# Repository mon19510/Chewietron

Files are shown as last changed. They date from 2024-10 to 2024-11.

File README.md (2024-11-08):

# Chewietron
Este repositorio contiene el código, modelos 3D y la documentación para un robot cuadrúpedo de 12 DOF, controlado mediante cinemática inversa. El objetivo es implementar un sistema de control que permita al robot realizar movimientos precisos y estáticos mediante el control de cada una de sus articulaciones. Fue nombrado en honor a mi perro, Chewie.

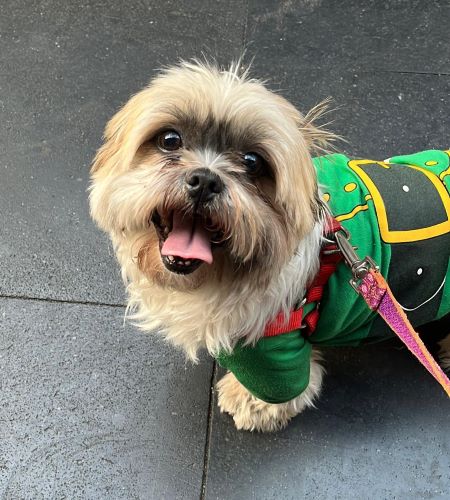
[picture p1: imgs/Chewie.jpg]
Chewie original


Este robot cuadrúpedo fue diseñado para estudiar y aplicar conceptos de cinemática inversa en un sistema físico. El robot cuenta con tres grados de libertad por pata, permitiéndole moverse de forma independiente en cada articulación. El control de cada servo se realiza utilizando un controlador PCA9685 conectado a un microcontrolador UM Tiny S3 (ESP32-S3), que calcula los ángulos de movimiento necesarios para cada pata con base en la posición deseada.

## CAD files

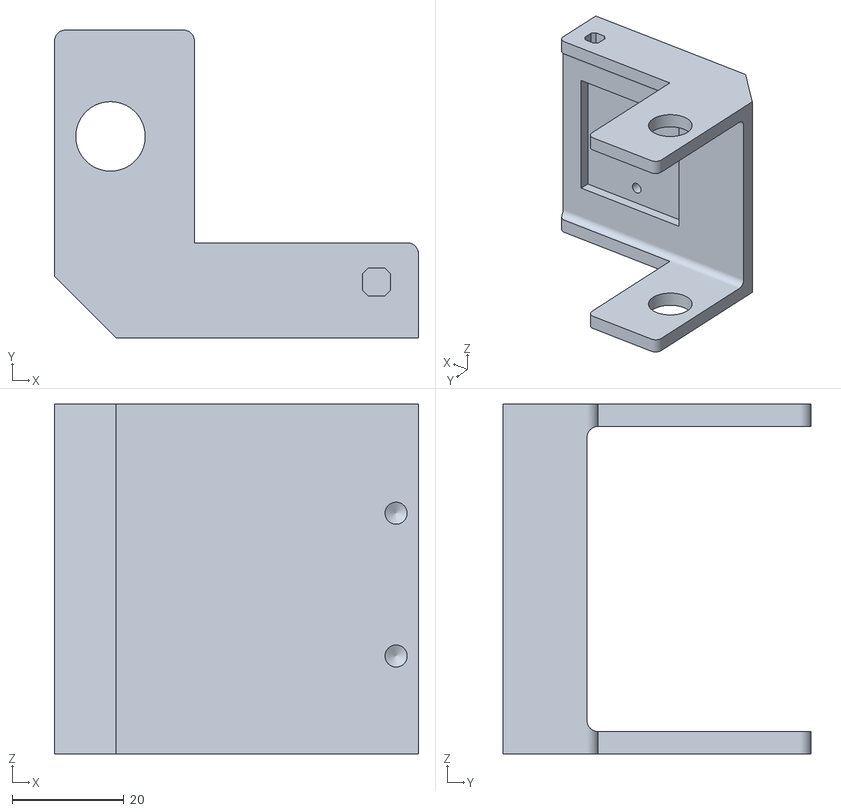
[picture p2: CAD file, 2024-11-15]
CADS/STLs GIT/BASEPRINCIPAL_PATA_DER_FRONTAL.stl
65.0 x 55.0 x 62.5

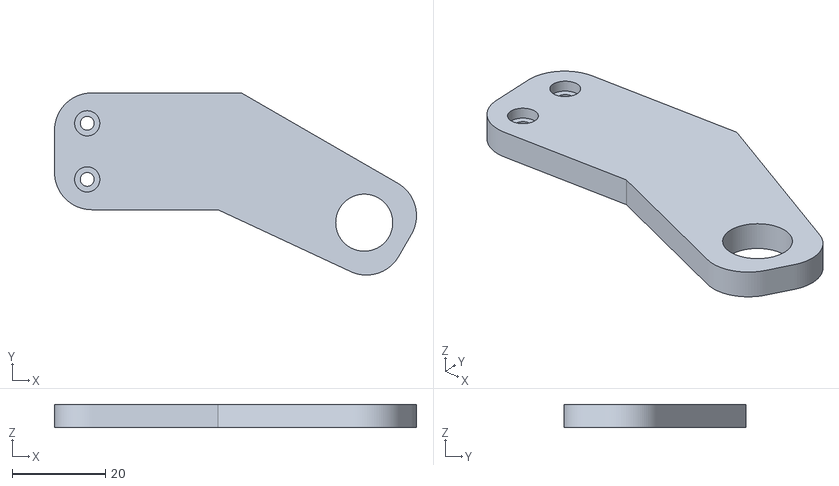
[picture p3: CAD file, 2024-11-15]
CADS/STLs GIT/PATA_SUP_DER_COJINETE.stl
77.5 x 39.0 x 5.00

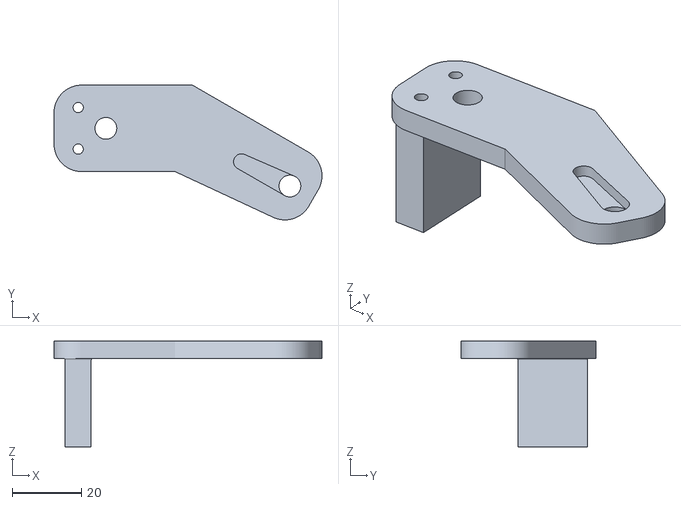
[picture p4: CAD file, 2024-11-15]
CADS/STLs GIT/PATA_SUP_IZQ_SIMPLE.stl
77.5 x 39.0 x 30.5

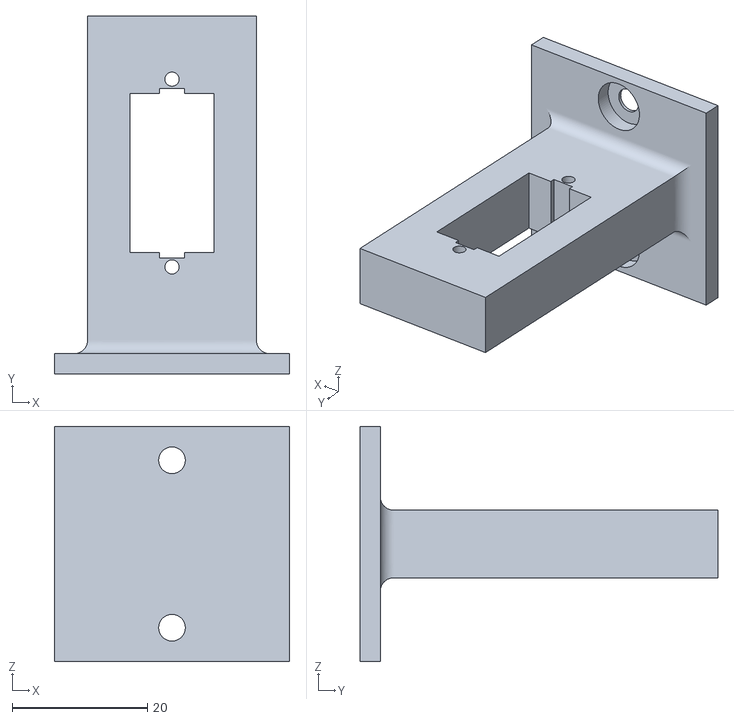
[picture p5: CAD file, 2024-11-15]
CADS/STLs GIT/BASEMOTOR_ENGRANE.stl
34.8 x 53.0 x 34.8

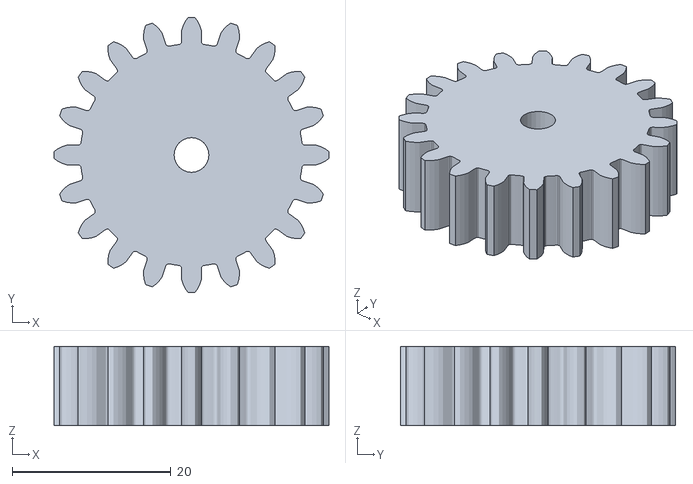
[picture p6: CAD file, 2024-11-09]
CADS/STLs GIT/ENGRANE_HOMBRO.stl
34.6 x 34.6 x 10.0

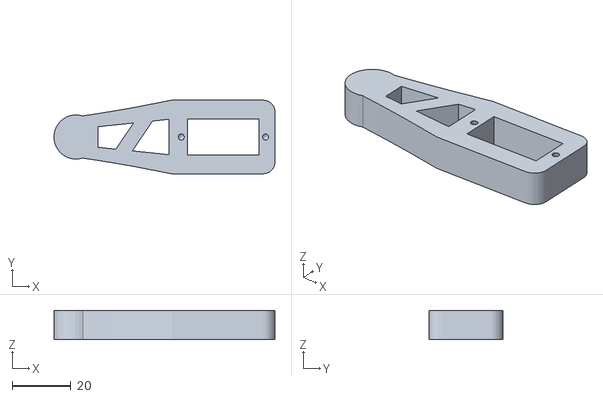
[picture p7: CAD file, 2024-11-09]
CADS/STLs GIT/PATA_INF.stl
75.0 x 25.0 x 10.0

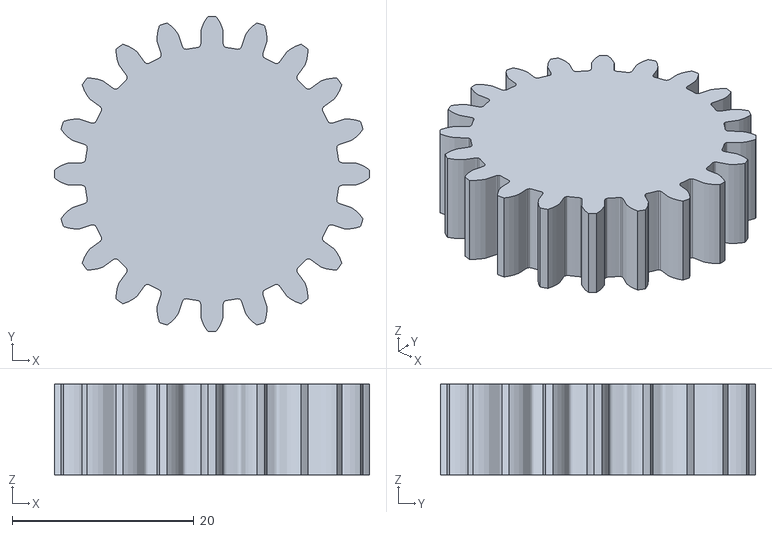
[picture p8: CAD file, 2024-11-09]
CADS/STLs GIT/ENGRANE_HELICE.stl
34.6 x 34.6 x 10.0

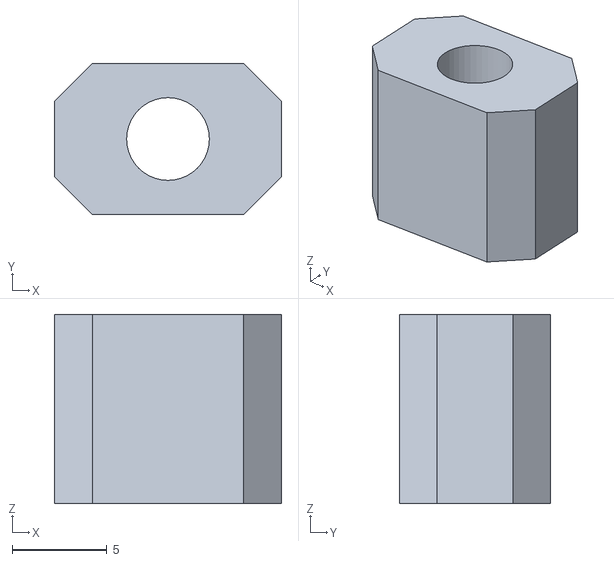
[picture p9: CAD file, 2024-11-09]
CADS/STLs GIT/CONECTOR_ENGRANE_HOMBRO.stl
12.0 x 8.00 x 10.0

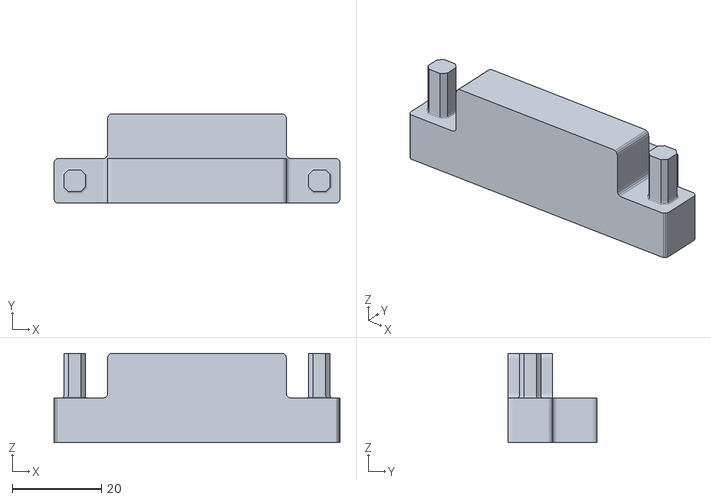
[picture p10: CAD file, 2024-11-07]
CADS/STLs GIT/UNION_CHEWIE.stl
64.0 x 20.0 x 20.0

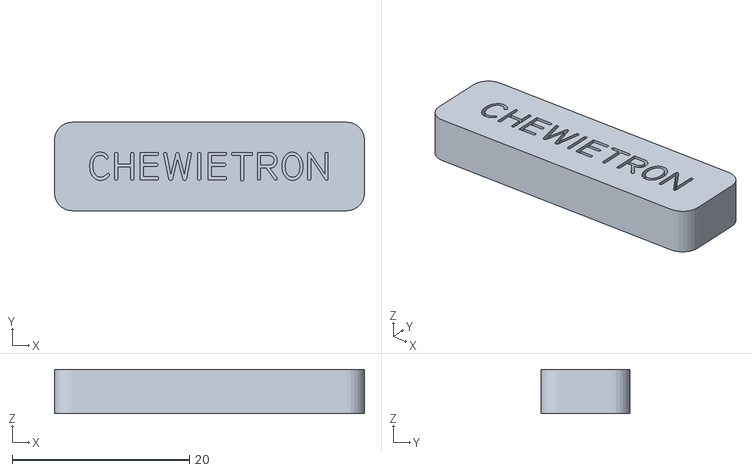
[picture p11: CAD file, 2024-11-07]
CADS/STLs GIT/TAG.stl
35.0 x 10.0 x 5.00

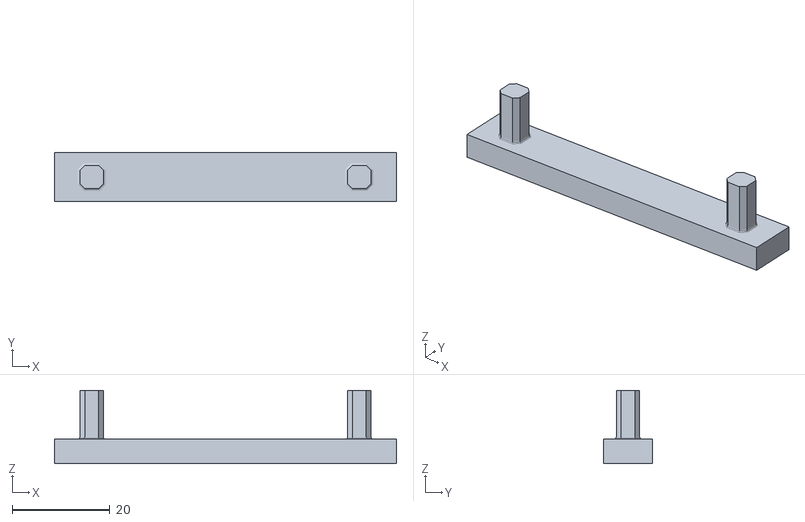
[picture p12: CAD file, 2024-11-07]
CADS/STLs GIT/UNION_INTERNA.stl
70.0 x 10.0 x 15.0

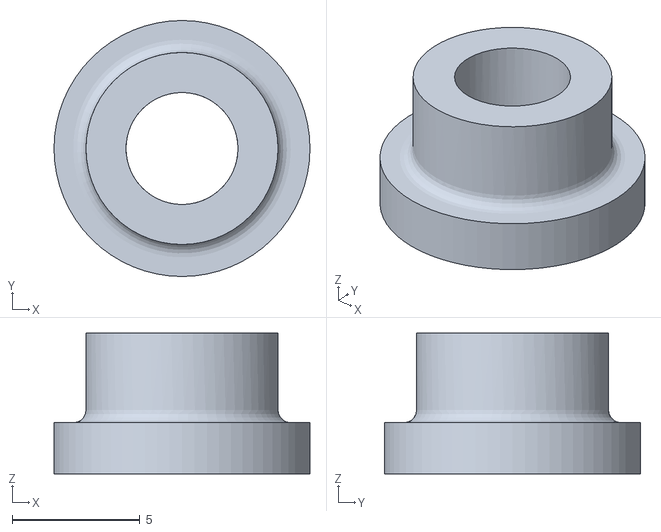
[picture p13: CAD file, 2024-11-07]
CADS/STLs GIT/ESPACIADOR.stl
10.0 x 10.0 x 5.50

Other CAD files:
CADS/STLs GIT/PATA_SUP_IZQ_COJINETE.stl
CADS/STLs GIT/BASEPRINCIPAL_PATA_IZQ_FRONTAL.stl
CADS/STLs GIT/PATA_SUP_DER_SIMPLE.stl
CADS/STLs GIT/BASEPRINCIPAL_PATA_DER_TRASERA.stl
CADS/STLs GIT/BASEPRINCIPAL_PATA_IZQ_TRASERA.stl
CADS/AS_GENERAL.iam
CADS/BASEMOTOR_ENGRANE.ipt
CADS/BASEMOTOR_HOMBRO.ipt
CADS/BASEPRINCIPAL_PATA_DER.ipt
CADS/BASEPRINCIPAL_PATA_IZQ.ipt
CADS/BASE_DE_PRUEBA.ipt
CADS/CONECTOR_ENGRANE_HOMBRO.ipt
CADS/EJE_TORNILLO.ipt
CADS/ENGRANE_HELICE.ipt
CADS/ENGRANE_HOMBRO.ipt
CADS/ESPACIADOR.ipt
CADS/HELICE_CRUZ.ipt
CADS/PARA_INF.ipt
CADS/PATA_SUP_DER.ipt
CADS/PATA_SUP_IZQ.ipt
CADS/Servo Motor hélice/OldVersions/Servo Motor hélice.0001.ipt
CADS/Servo Motor hélice/Part 1.ipt
CADS/Servo Motor hélice/Part 2.ipt
CADS/Servo Motor hélice/Servo Motor hélice.iam
CADS/Servo Motor hélice/Servo Motor hélice.ipt
CADS/Servo mockup/OldVersions/Servo mockup.0004.ipt
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

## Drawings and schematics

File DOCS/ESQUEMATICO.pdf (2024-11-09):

# M DULO DE BATERIAS

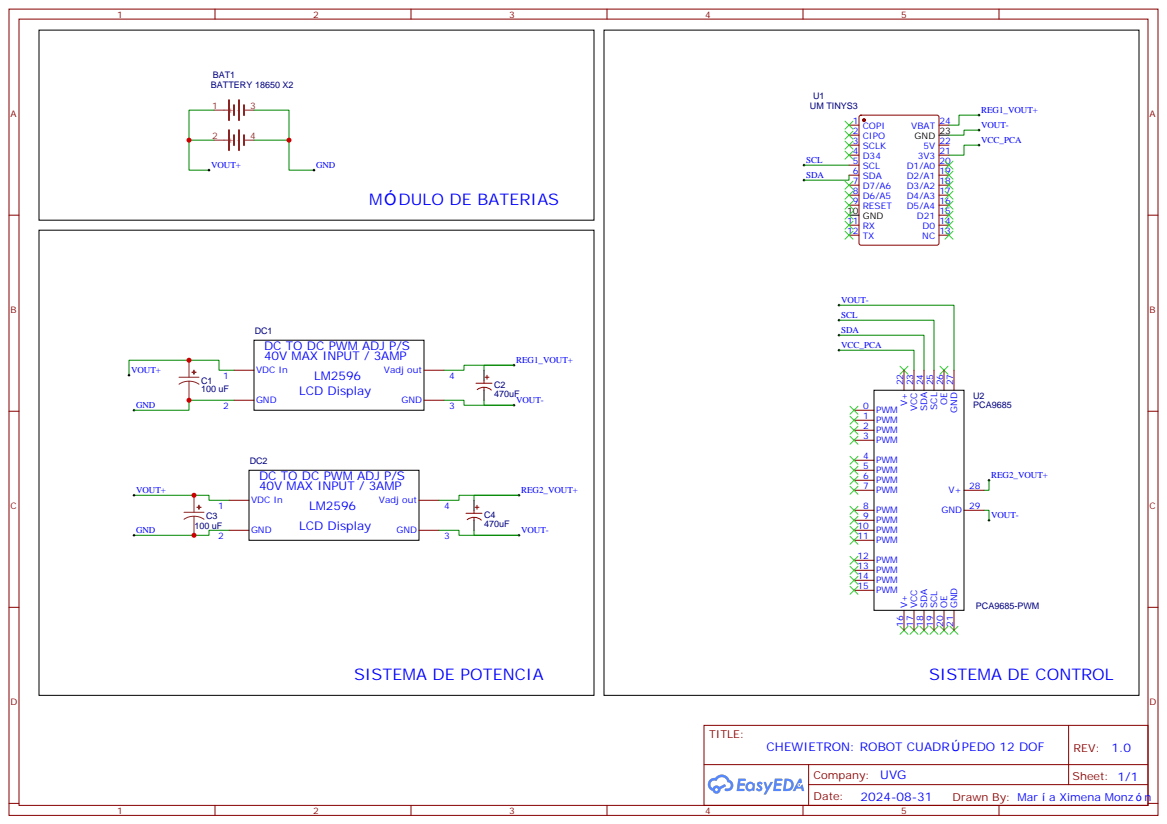
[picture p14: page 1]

DC TO DC PWM ADJ P/S
40V MAX INPUT / 3AMP

Drawn By: Mar a Ximena Monz n

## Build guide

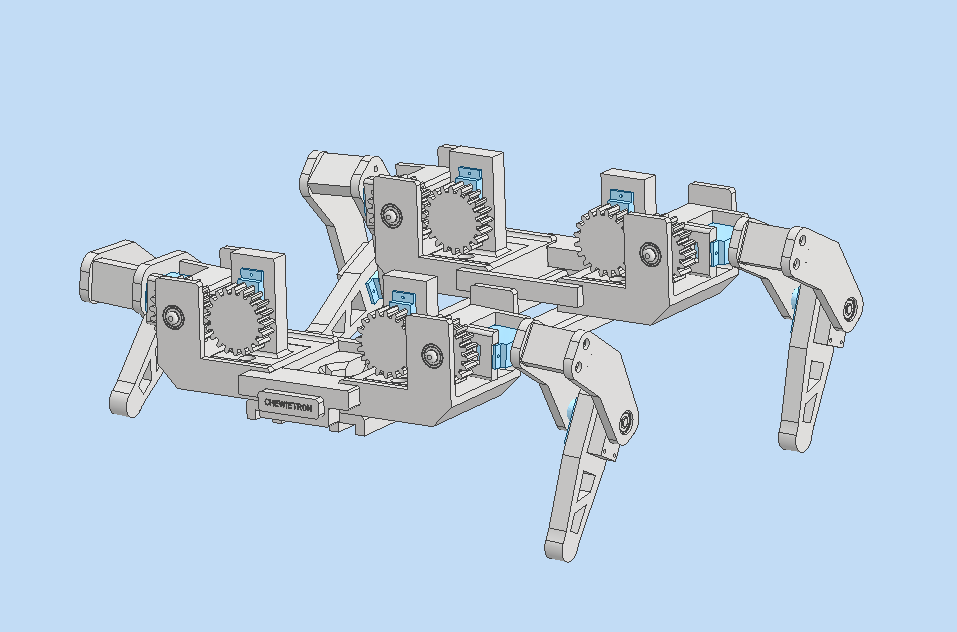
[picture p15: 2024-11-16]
imgs/Assembly_Chewietron.png

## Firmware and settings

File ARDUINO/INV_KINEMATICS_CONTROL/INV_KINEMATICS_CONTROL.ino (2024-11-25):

#include <Wire.h>
#include <Adafruit_PWMServoDriver.h>

// Configuración del PCA9685
Adafruit_PWMServoDriver pwm = Adafruit_PWMServoDriver(0x40);

// Configuración de los límites de pulso en microsegundos
#define SERVOMIN 1000   // Pulso mínimo para 0 grados
#define SERVOMAX 2000   // Pulso máximo para 180 grados

// Dimensiones de la pata en mm
float L_hip = 31.15; // Longitud de la cadera
float a1 = 77.80;    // Longitud del fémur
float a2 = 84.86;    // Longitud de la tibia

//Offset para grados de la cadera
//float theta1_offset = 15.0;

// Función para convertir ángulo a pulso PWM
int angleToPulse(int angle) {
  int pulseUs = map(angle, 0, 180, SERVOMIN, SERVOMAX);

  // Convierte el pulso en microsegundos a un valor que el PCA9685 entienda
  int pulsePCA9685 = pulseUs * 4096 / 20000;  // Ajuste para 50 Hz (20 ms por ciclo)
  
  return pulsePCA9685;
  }

// Función de cinemática inversa
void inverseKinematics(float x, float y, float z, float &theta1, float &theta2, float &theta3) {
  // Cálculo del ángulo de la cadera (theta1)
  theta1 = atan2(y, x) * 180 / PI;

  // Distancia proyectada en el plano horizontal (excluyendo la cadera)
  float r = sqrt(x * x + y * y) - L_hip;

  // Distancia total al punto objetivo
  float d = sqrt(r * r + z * z);

  // Cálculo del ángulo del fémur (theta2)
  theta2 = atan2(z, r) * 180 / PI + acos((a1 * a1 + d * d - a2 * a2) / (2 * a1 * d)) * 180 / PI;

  // Cálculo del ángulo de la tibia (theta3)
  theta3 = 180 - acos((a1 * a1 + a2 * a2 - d * d) / (2 * a1 * a2)) * 180 / PI;

  // Diagnóstico para depuración
  Serial.print("Theta1 (Cadera): "); Serial.println(theta1);
  Serial.print("Theta2 (Fémur): "); Serial.println(theta2);
  Serial.print("Theta3 (Tibia): "); Serial.println(theta3);
}

// Función para mover una pata
void moveLeg(float x, float y, float z, int servoCadera, int servoFemur, int servoTibia) {
  float theta1, theta2, theta3;

  // Calcular ángulos de las articulaciones
  inverseKinematics(x, y, z, theta1, theta2, theta3);

  // Convertir ángulos a pulsos PWM
  int pulse1 = angleToPulse(theta1);
  int pulse2 = angleToPulse(theta2);
  int pulse3 = angleToPulse(theta3);

  // Diagnóstico para depuración
  Serial.print("Pulse1 (Cadera): "); Serial.println(pulse1);
  Serial.print("Pulse2 (Fémur): "); Serial.println(pulse2);
  Serial.print("Pulse3 (Tibia): "); Serial.println(pulse3);

  // Enviar pulsos a los servos
  pwm.setPWM(servoCadera, 0, pulse1);
  pwm.setPWM(servoFemur, 0, pulse2);
  pwm.setPWM(servoTibia, 0, pulse3);
}

void setup() {
  Serial.begin(115200);  // Inicializar comunicación serial para depuración
  pwm.begin();           // Inicializar PCA9685
  pwm.setPWMFreq(50);    // Configurar frecuencia PWM a 50 Hz

  Serial.println("Iniciando control de pata con cinemática inversa");
}

void loop() {
  float x_centro = 109.0;
  float z_centro = -20.34; // Centro del semicírculo
  float radio = 15.0;      // Radio reducido para suavidad
  int pasos = 25;          // Número de pasos para la trayectoria
  float theta1_base = 0; //Angulo base de la cadera
  float Amplitud = 35.0; //Amplitud de oscilacion 
  float omega  = 1.0; //Frecuencia de oscilacion

  //Tiempo actual en segundos
  float t = millis()/1000.0;

  // **Movimiento de ida de la pata frontal derecha y lateral izquierda**

  for (int i = 0; i <= pasos; i++) {
    float t_norm = (float)i / pasos; // Normalizar t entre 0 y 1

    // Variación dinámica de theta1
    float theta1_dynamic = theta1_base + Amplitud * sin(omega * t);
    float theta1_rad = theta1_dynamic * PI / 180.0;

    // Interpolación sinusoidal para suavidad
    float x = x_centro + radio * cos(t_norm * PI);
    float z = z_centro - radio * sin(t_norm * PI); // Montañita suave
    float y = radio * cos(t_norm * PI) * sin(theta1_rad);

    // Mueve la pata frontal derecha y lateral izquierda
    moveLeg(x, y, z, 8, 9, 10);
    moveLeg(x, y, z, 4, 5, 6);
    delay(10);
  }

  // **Movimiento de regreso de la pata frontal derecha y lateral izquierda**
  for (int i = pasos; i >= 0; i--) {
    float t_norm = (float)i / pasos; // Normalizar t entre 0 y 1

    // Variación dinámica de theta1
    float theta1_dynamic = theta1_base + Amplitud * sin(omega * t);
    float theta1_rad = theta1_dynamic * PI / 180.0;

    // Interpolación sinusoidal inversa para el regreso
    float x = x_centro + radio * cos(t_norm * PI);
    float z = z_centro - radio * sin(t_norm * PI); // Montañita suave
    float y = radio * cos(t_norm * PI) * sin(theta1_rad);

    // Mueve la pata frontal derecha y lateral izquierda
    moveLeg(x, y, z, 4, 5, 6);
    moveLeg(x, y, z, 8, 9, 10);
    delay(10);
  }

  // **Movimiento de ida de la pata frontal izquierda y lateral derecha**
  for (int i = 0; i <= pasos; i++) {
    float t_norm = (float)i / pasos; // Normalizar t entre 0 y 1

    // Variación dinámica de theta1
    float theta1_dynamic = theta1_base + Amplitud * sin(omega * t);
    float theta1_rad = theta1_dynamic * PI / 180.0;

    // Interpolación sinusoidal para suavidad
    float x = x_centro + radio * cos(t_norm * PI);
    float z = z_centro - radio * sin(t_norm * PI); // Montañita suave
    float y = radio * cos(t_norm * PI) * sin(theta1_rad);

    // Mueve la pata frontal izquierda y lateral derecha
    moveLeg(x, y, z, 0, 1, 2);
    moveLeg(x, y, z, 12, 13, 14);
    delay(10);
  }

  // **Movimiento de regreso de la pata frontal izquierda y lateral derecha**
  for (int i = pasos; i >= 0; i--) {
    float t_norm = (float)i / pasos; // Normalizar t entre 0 y 1

    // Variación dinámica de theta1
    float theta1_dynamic = theta1_base + Amplitud * sin(omega * t);
    float theta1_rad = theta1_dynamic * PI / 180.0;

    // Interpolación sinusoidal inversa para el regreso
    float x = x_centro + radio * cos(t_norm * PI);
    float z = z_centro - radio * sin(t_norm * PI); // Montañita suave
    float y = radio * cos(t_norm * PI) * sin(theta1_rad);

    // Mueve la pata frontal izquierda y lateral derecha
    moveLeg(x, y, z, 0, 1, 2);
    moveLeg(x, y, z, 12, 13, 14);
    delay(10);
  }

}

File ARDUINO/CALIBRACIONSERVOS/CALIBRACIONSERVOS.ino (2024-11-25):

#include <Wire.h>
#include <Adafruit_PWMServoDriver.h>

Adafruit_PWMServoDriver pwm = Adafruit_PWMServoDriver(0x40);

// Definir los límites de pulso para el servo
#define SERVOMIN 1000   // Pulso mínimo para 0 grados
#define SERVOMAX 2000   // Pulso máximo para 180 grados

void setup() {
  Serial.begin(115200);
  pwm.begin();
  pwm.setPWMFreq(50);  // Configura la frecuencia para los servos (50 Hz)
  Serial.println("Prueba de ángulo de servo");
  Serial.println("Ingresa un ángulo entre 0 y 180 para probar:");
}

void loop() {
  if (Serial.available() > 0) {
    int angle = Serial.parseInt();
    angle = constrain(angle, 0, 180);  // Asegura que el ángulo esté entre 0 y 180
    pwm.setPWM(0, 0, angleToPulse(angle));
    Serial.print("Ángulo del servo: ");
    Serial.println(angle);
  }
}


int angleToPulse(int angle) {
  int pulseUs = map(angle, 0, 180, SERVOMIN, SERVOMAX);

  // Convierte el pulso en microsegundos a un valor que el PCA9685 entienda
  int pulsePCA9685 = pulseUs * 4096 / 20000;  // Ajuste para 50 Hz (20 ms por ciclo)
  
  return pulsePCA9685;
}

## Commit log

2024-10-05 CADS
    Current version for 3D printed parts of Chewietron.
    [AS_GENERAL.0004.iam, AS_GENERAL.iam, BASEMOTOR_ENGRANE.ipt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]
2024-11-07 Comunicacion I2C
2024-11-09 PCB y Esquematico
    [Drill_NPTH_Through.DRL, Drill_PTH_Through.DRL, Drill_PTH_Through_Via.DRL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]
